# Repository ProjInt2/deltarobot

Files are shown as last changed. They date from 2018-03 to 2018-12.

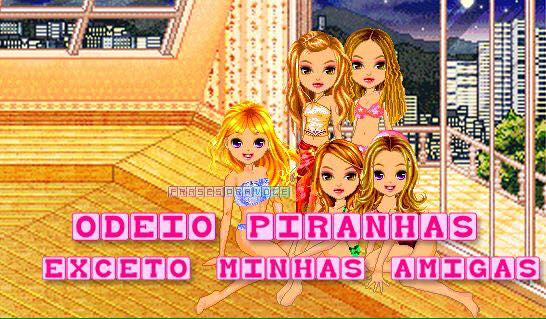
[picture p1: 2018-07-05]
sw/deltarobot-gui/res/amigas.jpg

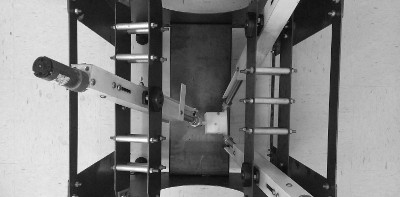
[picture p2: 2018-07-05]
sw/deltarobot-gui/res/menu-header.jpg

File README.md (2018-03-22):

# Delta Robot Actuation Project

*by Lucas Camargo, Soly Waltrick, and Willian Kenji Nishizawa*

This project consists in the development of a driving and control solution for a standard delta robot. It does not concern the development of the robot itself, or its actuators. It focuses on driving the actuators, control mechanisms, and required transducers (sensors).

The deliverables are organized in the following directories:

+ *datasheets* - documentation on different components used in the project
+ *fw* - controller + driver: board firmware
+ *hw* - controller + driver: hardware project
+ *report* - project report
+ *sw* - interface software for interacting with the controller board using a computer

*TODO: insert backref link to post*

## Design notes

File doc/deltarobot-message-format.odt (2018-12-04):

deltarobot Message Format and Parsing Library

Specification v1.0

Lucas Pires Camargo

EMB5613 – Projeto Integrado de Sistemas Embarcados

Prof. Diego Santos Greff

# Introduction

This document defines the message formats used by deltarobot. They are to be used in the implementation of both the firmware and the accompanying software interface.

For more information on the nature of the project and the robot itself, please refer to the full report.

## Purpose

The project aims for making the platform fully operational, which means giving the user means of controlling the platform position. This could be accomplished with an interface on the controller device itself, but we figure it is better (and more simply) done by use of a personal computer connected to the platform. This makes possible the use of an user interface with interactive 3D graphics, the creation of a software library for integration into other applications, path drawing, etc.

However, to accomplish this, there must be a standardized way for the controller to talk to a personal computer. Therefore, it was decided that a simple protocol would have to be defined.

## Definitions

In this specification, “Controller” means the device that operates the motors of the parallel actuators, reads sensor inputs, and executes the control loop. “Interface”, “Interface software”, or “Host” refers to the computer that is communicating with the Controller, monitoring its status, and defining its goal positions.

An “Opcode” is be understood as “Operation code”. Different Opcodes describe the various functionalities of the protocol in compartmentalized commands.

## About this specification

This document is organized as follows:

- Section “Connection and Transmission” gives an overview on the physical link layer.
- Section “Message Frame Structure” defines the basic structure of a command.
- Section “Opcodes” defines commands, their requirements and outcomes.
- Section “Implementation Notes” gives further details in regards to implementation and noteworthy behaviors.

# Connection and Transmission

The Controller is to be connected to the Host by means of a serial port device. This device has to be configured as follows:

- Baud rate: 115200 baud
- Data bits: 8 bits
- Stop bits: 1 bit
- Parity bits: (none)
- Hardware flow control: (disabled)

Furthermore, a “serial port”, this can mean a physical, standard RS-232 connection, or a connection emulated in software or in hardware. A valid implementation is a USB connection through which a serial data stream is sent, and that the Host can recognize as such. This has to translate into a COM port or TTY device file (“/dev/ttyS?”, “/dev/ttyUSB?”) in the operating system of the Host, to which the Interface Software connects.

Communication is full-duplex, that is, there can be a transmission occurring from both sides simultaneously. Every valid piece of communication is define in terms of “message frames”. A message frame is a group of bytes with a defined start and end, means for verification, and a specific purpose. The next section goes into detail about the structure of a message frame and related definitions.

# Message Frame Structure

Commands, status information, and control information are organized into frames. A frame is a validated sequence of bytes structured as follows:

Starter | Opcode | Data Length | Data | Checksum | Terminator
‘$’ (ASCII) | “What the frame is” | How many data bytes | Opcode-dependant | (See below) | ‘:’ (ASCII)
1 byte | 1 byte | 1 byte | (length – 5) bytes | 1 byte | 1 byte

- Starter: this marker (ASCII character ‘$’) denotes the beginning of a transmission frame. Both the Controller and the Host scan the incoming stream of bytes, expecting to find this marker. When it is found, decoding of a frame starts.
- Opcode: “operation-code”, a single byte from a predefined list. Individual opcodes are discussed in greater detail in a further section.
- Data Length: how many bytes of data the message contains. The value is usually tied to the opcode, but may vary (up to 255 bytes).
- Data: the data bytes of the message. Again, their meaning is opcode-specific.
- Checksum: a code that is calculated from the contents of the message. It is used to ascertain that the message has been received correctly. How the checksum is calculated is presented on the next section.
- Terminator: a single terminator byte (ASCII character ‘:’) that indicates the end of a message.

## Checksum Calculation

Checksums are calculated as a modular sum of all the bytes of the message, including starter and terminator. A modular sum is defined, in this context, as adding the bytes contents to an accumulator (initialized with zero), one after the other. Following every sum, the accumulator is set to its own value modulo 256.

This can be implemented by repeatedly summing the byte values to an unsigned byte variable.

## Notes

- There is no message resend requests.
- Incomplete or corrupted packets are lost.
- If an ACK times out, the operation request has to be repeated, depending on the opcode.

# Opcodes

This section describes each opcode in detail. However, for the purpose of an overview, a complete list is given beforehand. The opcodes are divided in three categories: “common” opcodes that can be sent in both directions, “down” opcodes that only make sense from Host to Controller, and “up” opcodes that only apply in the Controller to Host direction.

Following the lists of opcodes, there is a section explaining each opcode in detail.

## List of Common Opcodes

- Acknowledge – 0x41 – ASCII ‘A’
- No-Acknowledge – 0x4E – ASCII ‘N’

## List of Down Opcodes

- Homing Request – 0x48 – ASCII ‘H’
- Move Request – 0x4D – ASCII ‘M’
- Status Request – 0x53 – ASCII ‘S’
- Cancel Request – 0x43 – ASCII ‘C’

## List of Up Opcodes

- Homing Finished – 0x68 – ASCII ‘h’
- Move Finished – 0x6D – ASCII ‘m’
- Status Report – 0x73 – ASCII ‘s’
- General Error – 0x65 – ASCII ‘e’

## Acknowledge – 0x41 – ‘A’

Description: This opcode is a general acknowledgement (ack) message, to be issued in response to a previous request. It depends on the specific request (opcode) if it requires a corresponding ack or not. The message signifies that the request was understood, considered valid, and will be attempted to be fulfilled. If that is not the case, a No-Acknowledge (0x4E) is to be issued instead.

Data length: 1 byte

Data fields:

Data

Original Opcode

1 byte

There is only a single data field: one byte containing the opcode that prompted the Acknowledge.

Expected behavior: Opcode-specific. Generally none.

## No-Acknowledge – 0x4E – ‘N’

Description: This opcode is a general non-acknowledgement (nack) message, to be issued in response to a previous request. It depends on the specific request (opcode) if it requires a corresponding ack/nack or not. The message signifies that the request was not understood, considered invalid, or can’t be fulfilled at this current time. It is the negative alternative to the Acknowledge (0x41) opcode.

Data length: 1 byte

Data fields: There is only a single data field: one byte containing the opcode that prompted the NACK.

Data

Original Opcode

1 byte

## Homing Request – 0x48 – ‘H’

Description: This opcode is a request for the Controller to home in the actuators to a known default state. The specific behavior depends on the controller implementation, but is is expected to be something similar to retracting the arms until the stops are reached, defining the zero-movement state.

Data length: 0 bytes (none)

Data fields: This opcode has no associated data fields.

## Move Request – 0x4D – ‘M’

Description: This opcode is a request for the Controller to move the platform to a specified position. The path followed is expected to be linear.

Data length: TBD

Data fields: This opcode has the following data fields:

Data
DA – float | DB – float | DC – float
4 bytes | 4 bytes | 4 bytes

- Data field DA – displacement of arm “A” – 4 bytes – IEEE 32-bit float
- Data field DB – displacement of arm “B” – 4 bytes – IEEE 32-bit float
- Data field DC – displacement of arm “C” – 4 bytes – IEEE 32-bit float

## Status Request – 0x53 – ‘S’

Description: This opcode queries the Controller to send a status report message to the Host.

Data length: 0 bytes (none)

Data fields: This opcode has no associated data fields.

## Cancel Request – 0x43 – ‘C’

Description: This opcode requests the Controller to cancel the currently executing operation (Homing or Moving).

Data length: 0 bytes (none)

Data fields: This opcode has no associated data fields.

## Homing Finished – 0x68 – ASCII ‘h’

Description: This opcode informs the Host that the homing process has finalized.

Data length: 0 bytes (none)

Data fields: This opcode has no associated data fields.

## Move Finished – 0x6D – ASCII ‘m’

Description: This opcode informs the Host that the Controller moved the platform to the desired position.

Data length: 0 bytes (none)

Data fields: This opcode has no associated data fields.

## Status Report – 0x73 – ASCII ‘s’

Description: This opcode informs the Host of the current status of the Controller and the platform.

Data length: 13 bytes

Data fields: This opcode has the following data fields:

Data
STAT | DA – float | DB – float | DC – float
1 byte | 4 bytes | 4 bytes | 4 bytes

- STAT – Status bitmask – 1 byte
  - This byte is a bitmask containing information on the status of the platform:

STAT bits
7 | 6 | 5 | 4 | 3 | 2 | 1 | 0
RESERVED | RESERVED | RESERVED | STPC | STPB | STPA | ST1 | ST0

  - ST[0..1]: Status bits
    - Value 00: Platform is Idle
    - Value 01: Platform is Homing
    - Value 10: Platform is Moving
    - Value 11: Platform is at Error
  - STPA: bit indicating the status of the end-of-course switch of arm A.
    - Value 1: pressed
    - Value 0: not pressed
  - STPB: bit indicating the status of the end-of-course switch of arm B (1 means pressed).
  - STPC: bit indicating the status of the end-of-course switch of arm C (1 means pressed).
  - Bits 5-7 are reserved for use in future revisions.
- Data field DA – displacement of arm “A” – 4 bytes – IEEE 32-bit float
- Data field DB – displacement of arm “B” – 4 bytes – IEEE 32-bit float
- Data field DC – displacement of arm “C” – 4 bytes – IEEE 32-bit float

Note: If any arm displacement field is a NAN value, the arm position is unknown, and the Controller requires a Homing operation.

## General Error – 0x65 – ASCII ‘e’

Description: This opcode informs the Host that the platform has encountered an error and the current operation cannot continue.

Data length: 0 bytes (none)

Data fields: This opcode has no associated data fields.

# Parsing Library

The reference implementation of the protocol is a portable “pure-C” function library with no external dependencies, not even on the C standard library. This makes it suitable not only for use on a desktop application, but also for the controller firmware. Using the same implementation on both ends of the communication simplifies implementation on both ends and ensures code consistency.

The library is comprised of two files, a “.h” header and a “.c” source. Both files can be included in a source file for convenience, provided the definition.

## Usage

The library provides facilities for sending, parsing and receiving frames. It is comprised of two main data structures, some definitions, and three functions. The definitions and functions are covered in the following sections.

The first structure is protocol_data, a circular buffer used for storing streamed bytes for parsing. The function dp_process() function is used to add bytes to the buffer, and the dp_recv() function attempts to parse bytes of the buffer into a message.

A message is stored in the protocol_msg. The function dp_recv() stores a received message in it, and the function

The following section goes into the library interface in greater detail.

## Interface

### Return Codes

The library defines common integer return codes for the functions. According to C convention, a function returning 0 usually means the operation completed successfully or returned something meaningful.

The return code definitions start with the DP_RC_ prefix.

Return Code | Description
DP_RC_SUCCESS | The operation completed successfully.
DP_RC_ERROR_GENERIC | There was an error completing the operation.
DP_RC_NO_FRAME | No frame was available in the buffer.
DP_RC_OVERFLOW | Some buffer contents were lost because an overflow occurred.
DP_RC_GARBAGE | There was garbage in the buffer and no frame could be parsed.

### Functions

Return Code | Description
dp_process() | Insert incoming bytes into a protocol_data structure. Arguments: protocol_data *data → which buffer to insert data in int bytes → how many bytes to insert void *buf → where the data is
dp_recv() | Analyzes protocol data to look for a message, possibly returning it. Arguments: protocol_data *data → which buffer to parse from protocol_msg *msg → the message to fill out with parsed data
dp_send() | Sends a message using the given send function. Arguments: protocol_msg *msg → the message to be sent send_func_t f → the function that will be fed with the resulting stream bytes void *usr → opaque pointer that will be forwarded as an argument to the send function

### Structure protocol_msg

Type | Field | Description
uint8_t | opcode | Message opcode.
int | data_s | How many data bytes the message has.
char[32] | data | Data bytes of the message
int | checksum_ok | Flag indicating if the checksum was correct when parsed.

### Structure protocol_data

Type | Field
uint8_t | opcode
int | data_s
char[32] | data

### Other definitions

Identifier | Description
send_func_t | Type definition the the send function used by dp_send(). Defined as: typedef int (*send_func_t)(void *buf, int bytes, void *usr);
DP_PROTO_FRAME_START | Frame start marker (‘$’)
DP_PROTO_FRAME_END | Frame end marker (‘:’)
DP_PROTO_ALL_OPCODES | Character string containing all valid opcodes.
DP_OPCODE_ACK DP_OPCODE_NACK DP_OPCODE_HOMING DP_OPCODE_STATUS DP_OPCODE_MOVE DP_OPCODE_CANCEL DP_OPCODE_HOMING_REPL DP_OPCODE_STATUS_REPL DP_OPCODE_MOVE_REPL DP_OPCODE_GENERAL_ERR | Defines for every single opcode, for ease of use of the library.

## Examples

The library includes two example programs, in the tests/ directory.

- “cross_comm.cpp” → instantiates several library structures and sends messages back and forth, testing the main functionality in thre process.
- “send_opcode.cpp” → sends a simple ACKNOWLEDGE message on the serial port, to test basic communication functions.

deltarobot Message Format – spec v1.0 Page 11 of 11

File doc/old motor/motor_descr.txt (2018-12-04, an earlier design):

Boa tarde, 
Sou Lucas Camargo, aluno de Engenharia Mecatrônica da UFSC. Recebi seu contato por meio do Prof. Diego Greff. Ele deve ter mencionado a nossa necessidade de adquirir um motor similar a um que tínhamos em um projeto legado do laboratório. É um modelo pequeno com caixa de redução. Ocorreu dano ao rolamento do motor original , e na tentativa de conserto, as escovas foram quebradas.
Infelizmente não temos as informações de chapa dele, porque é antigo e isso se perdeu. A única informação que temos é o fabricante, Bühler. Porém posso dar algumas características gerais e fotos: 
- Comprimento do enrolamento: 45 mm
- Diâmetro do enrolamento: 20 mm
- Comprimento do íma permanente: 37 mm
- Diâmetro da carcaça: 30 mm

A ideia é encontrar um motor (ou três deles - para uma máquina paralela) que seja parecido.
Desde já já agradeço a atenção.

att,
Lucas

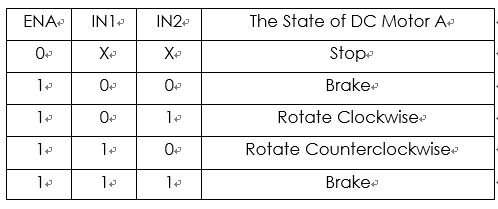
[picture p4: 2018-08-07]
datasheets/l298n-module/Motor Driver Module-L298N - Wiki_arquivos/Motor5.png

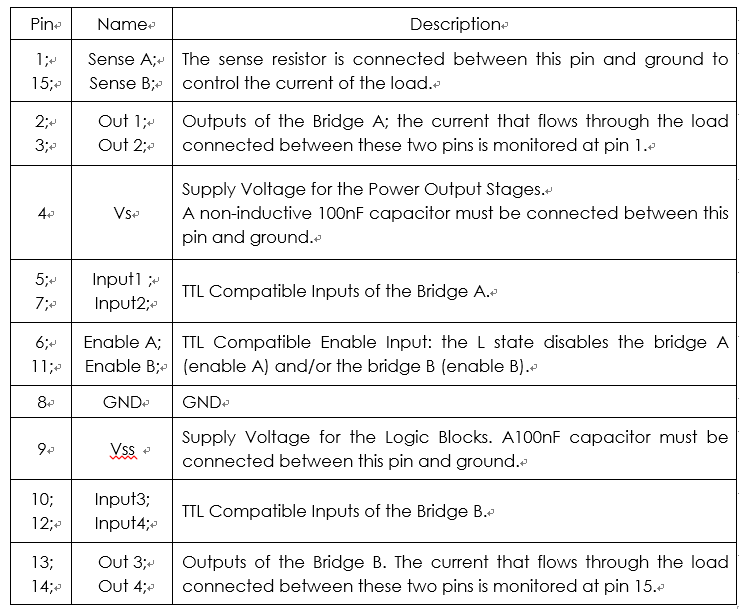
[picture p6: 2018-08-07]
datasheets/l298n-module/Motor Driver Module-L298N - Wiki_arquivos/Motor4.png

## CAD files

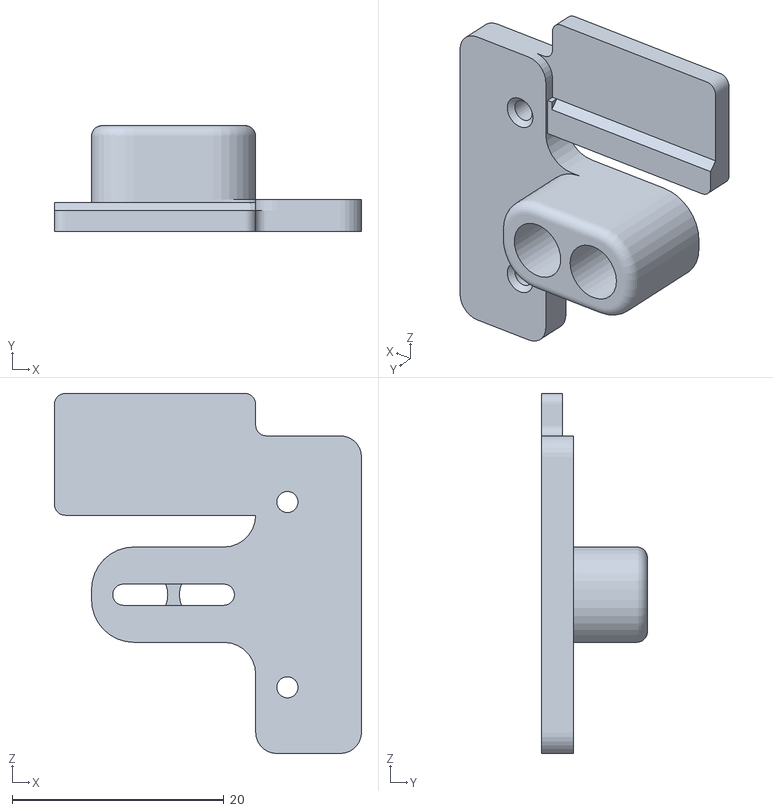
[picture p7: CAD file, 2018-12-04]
mec/optical_sw_holder_no_pins_larger_holes.stl
29.0 x 10.0 x 34.0

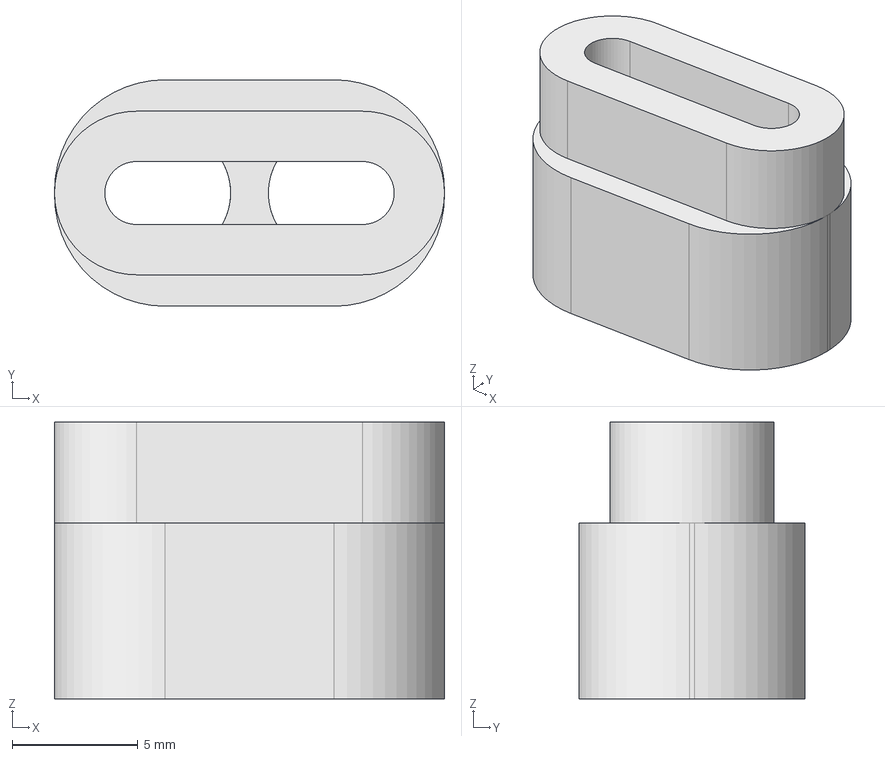
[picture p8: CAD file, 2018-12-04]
mec/optical_holder.fcstd
15.5 x 9.00 x 11.0 mm

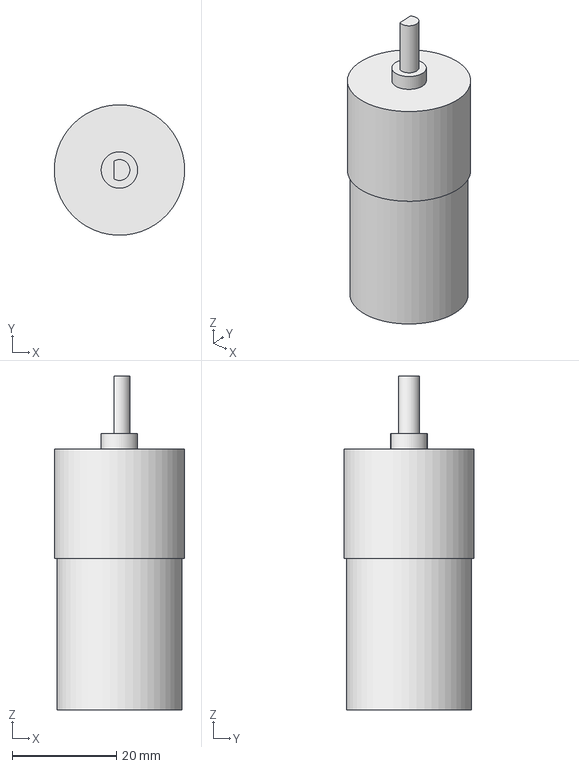
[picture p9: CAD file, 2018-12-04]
mec/motor.fcstd
25.0 x 25.0 x 64.0 mm

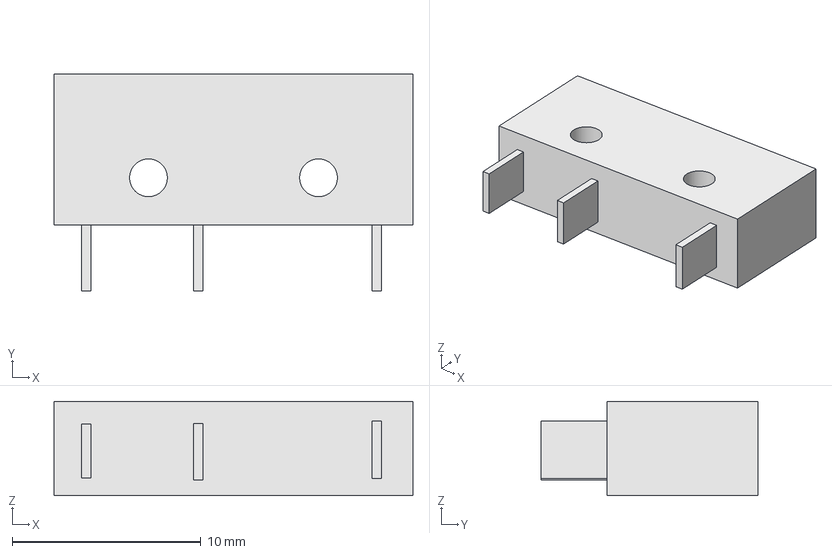
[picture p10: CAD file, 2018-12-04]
mec/stopper_sw.fcstd
19.0 x 11.5 x 5.00 mm

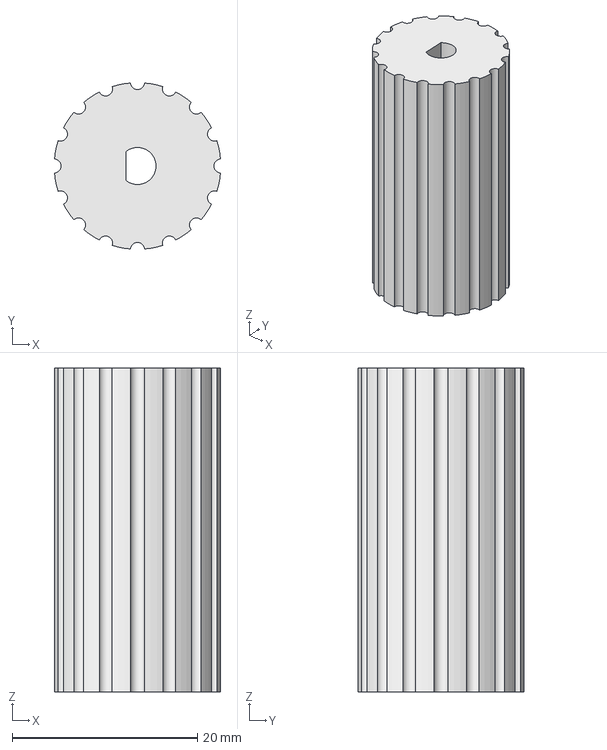
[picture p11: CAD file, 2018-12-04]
mec/axle_adapter.fcstd
17.9 x 17.9 x 35.0 mm

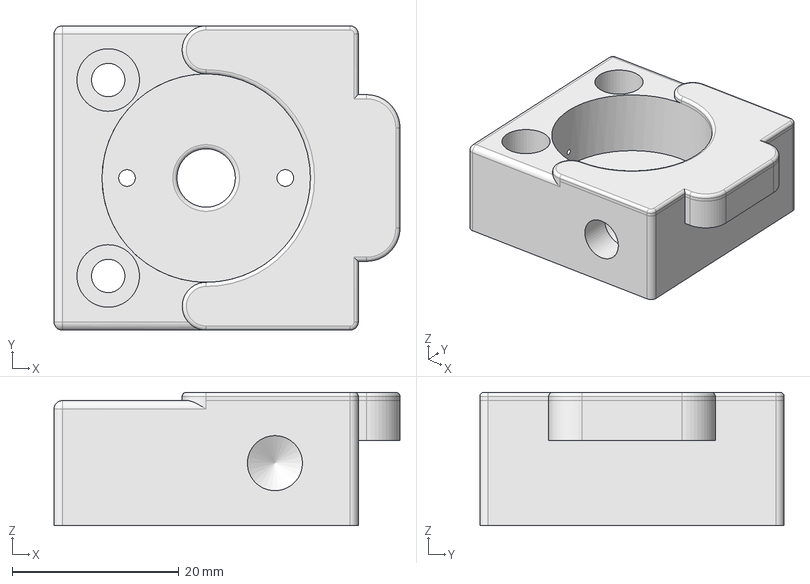
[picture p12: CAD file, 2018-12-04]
mec/stopper.fcstd
41.5 x 36.5 x 16.0 mm

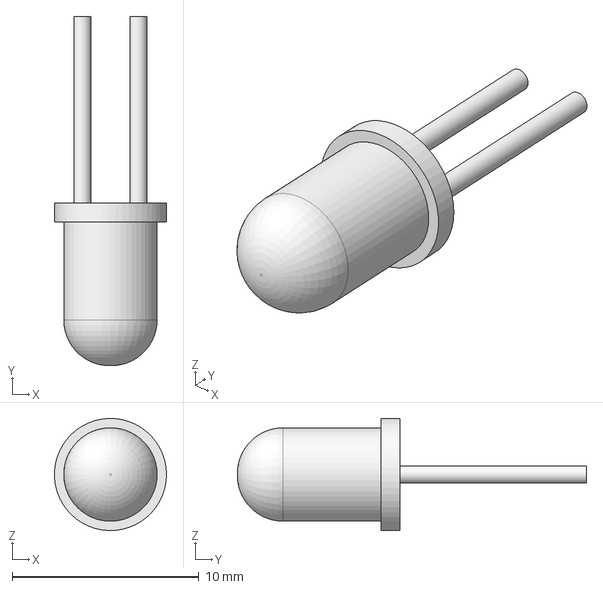
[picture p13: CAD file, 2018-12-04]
mec/led5mm.fcstd
5.99 x 18.7 x 6.00 mm

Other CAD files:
mec/assembly.fcstd
mec/optical_sw_holder_no_pins.stl
mec/optical_sw_holder.fcstd
mec/optical_sw_holder.stl

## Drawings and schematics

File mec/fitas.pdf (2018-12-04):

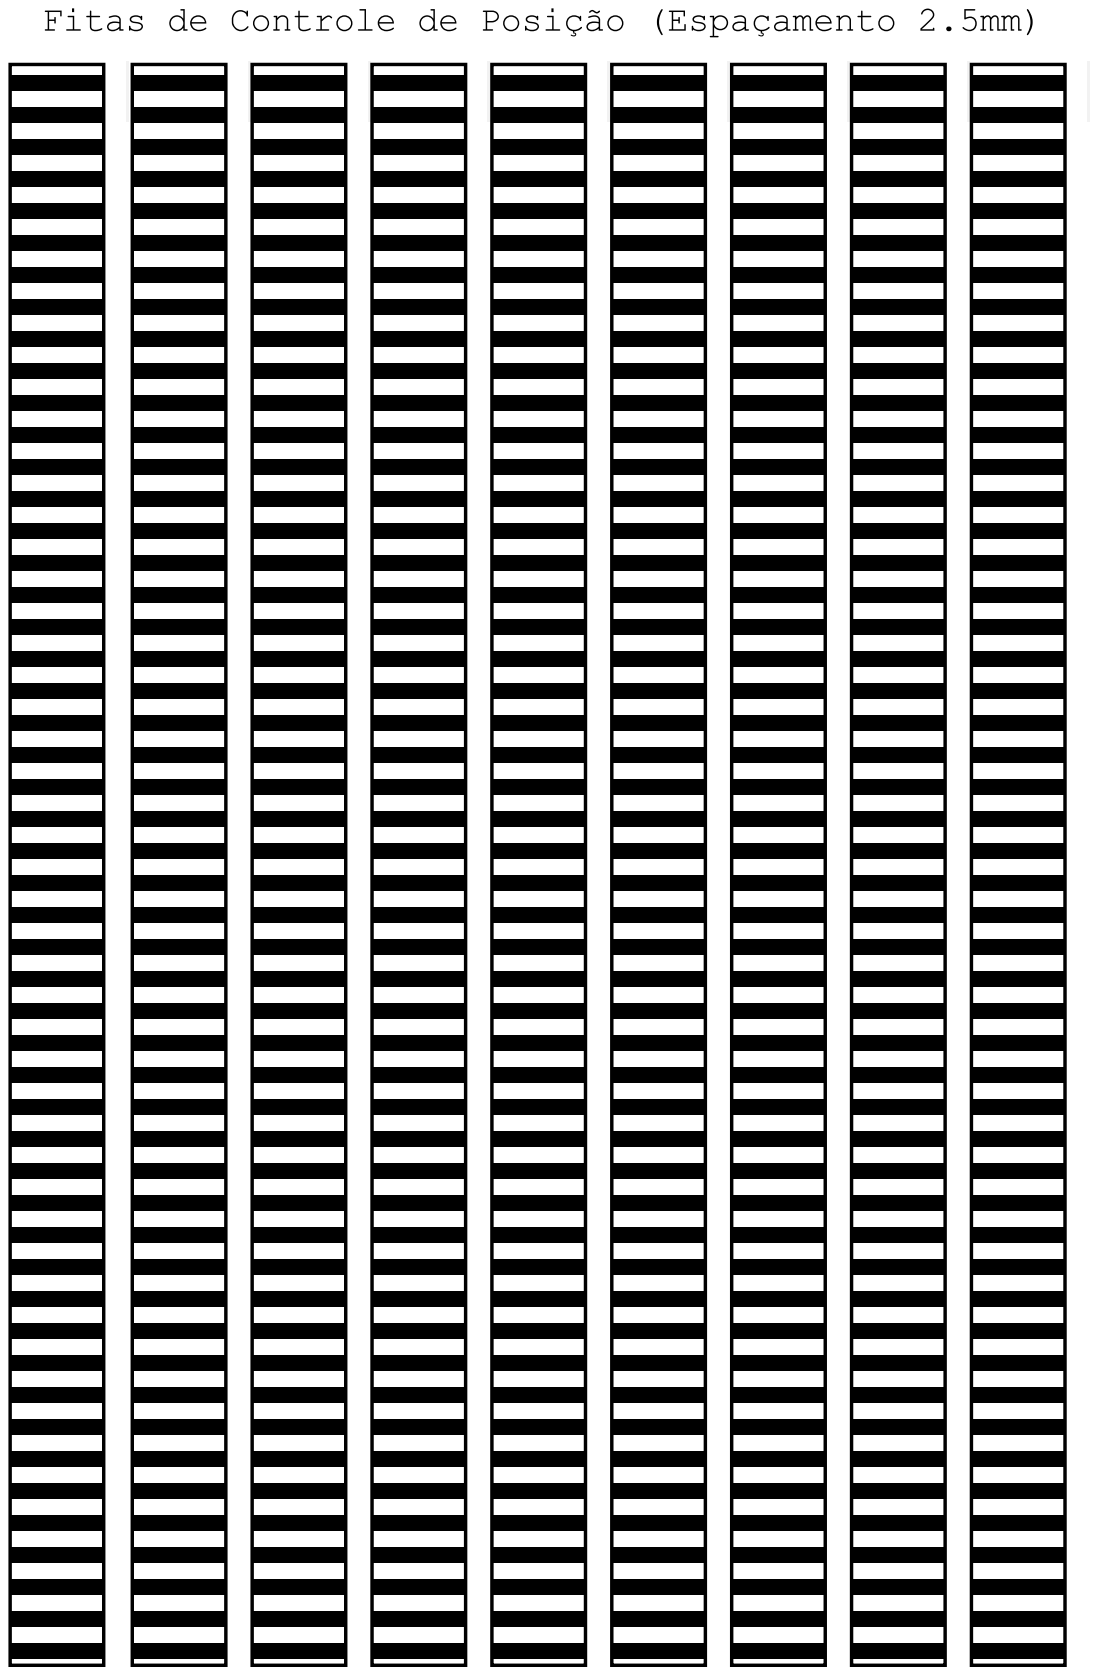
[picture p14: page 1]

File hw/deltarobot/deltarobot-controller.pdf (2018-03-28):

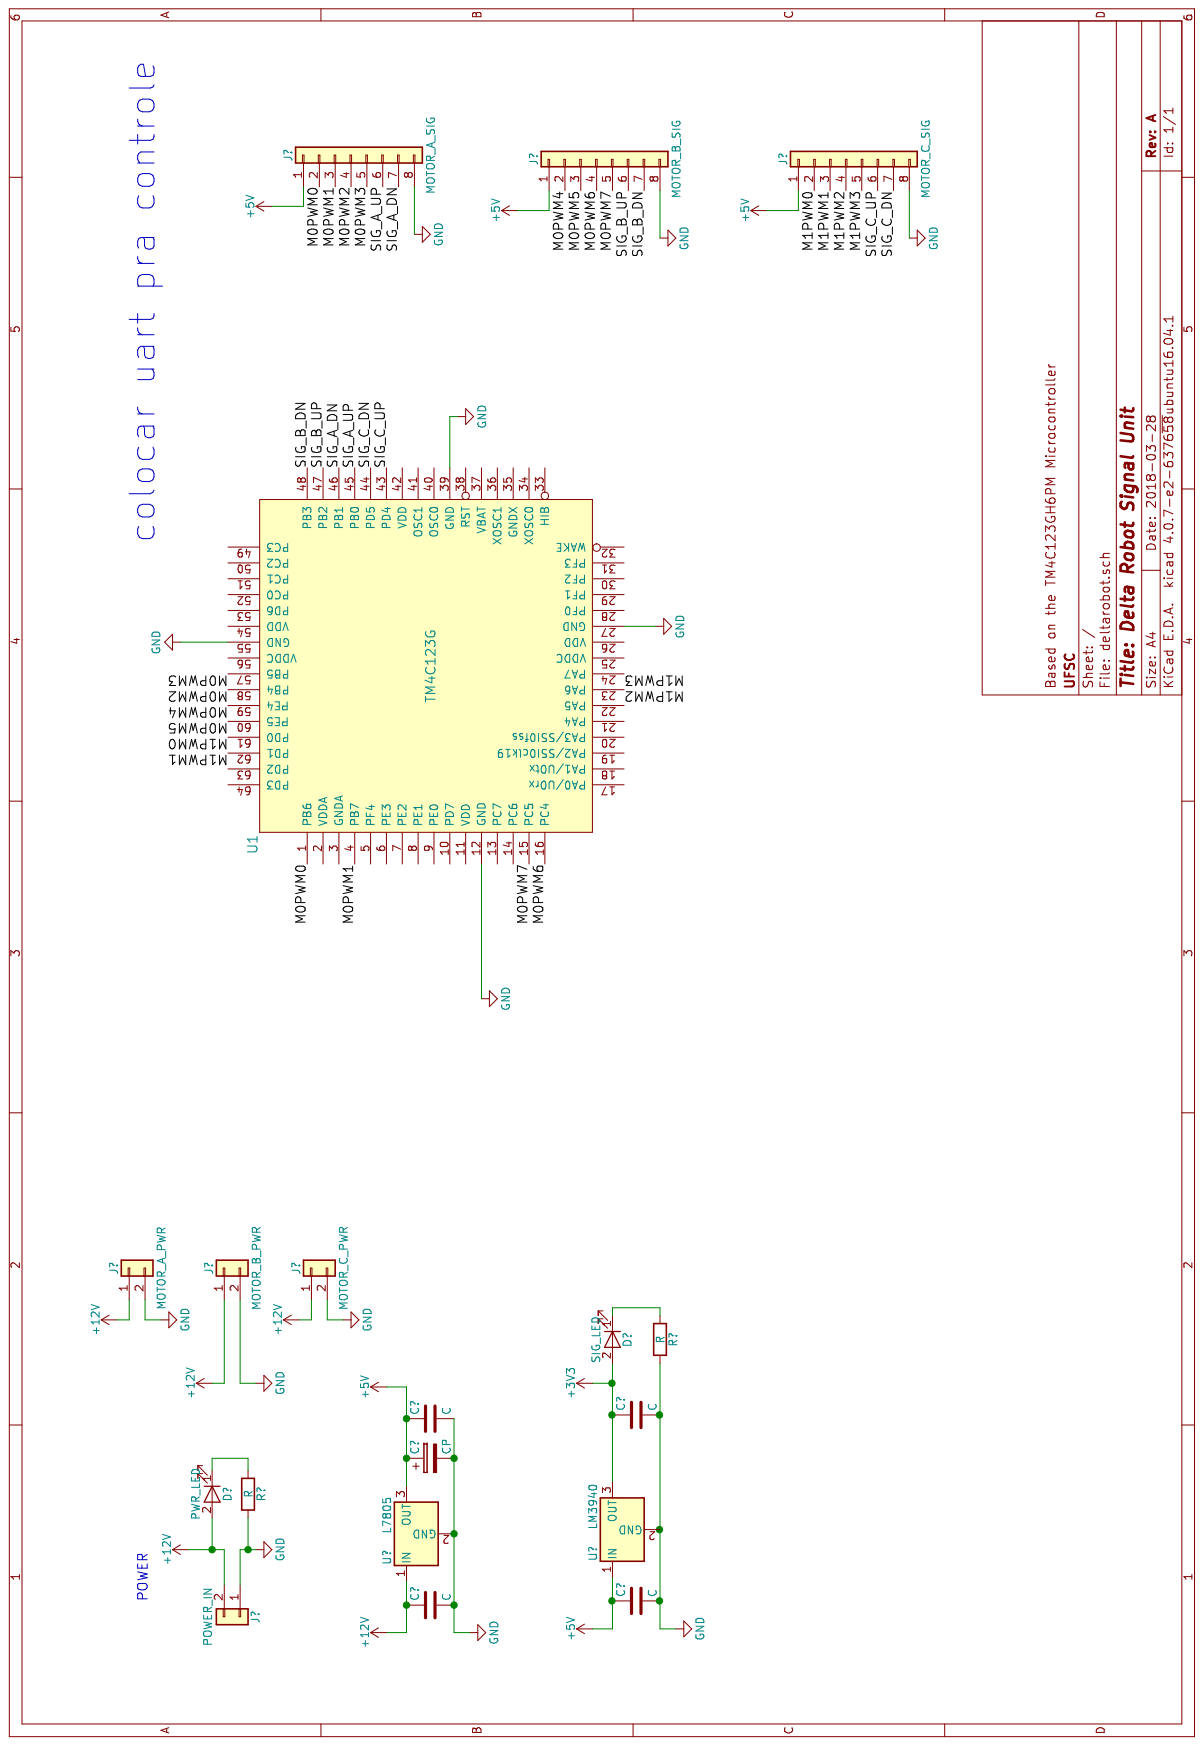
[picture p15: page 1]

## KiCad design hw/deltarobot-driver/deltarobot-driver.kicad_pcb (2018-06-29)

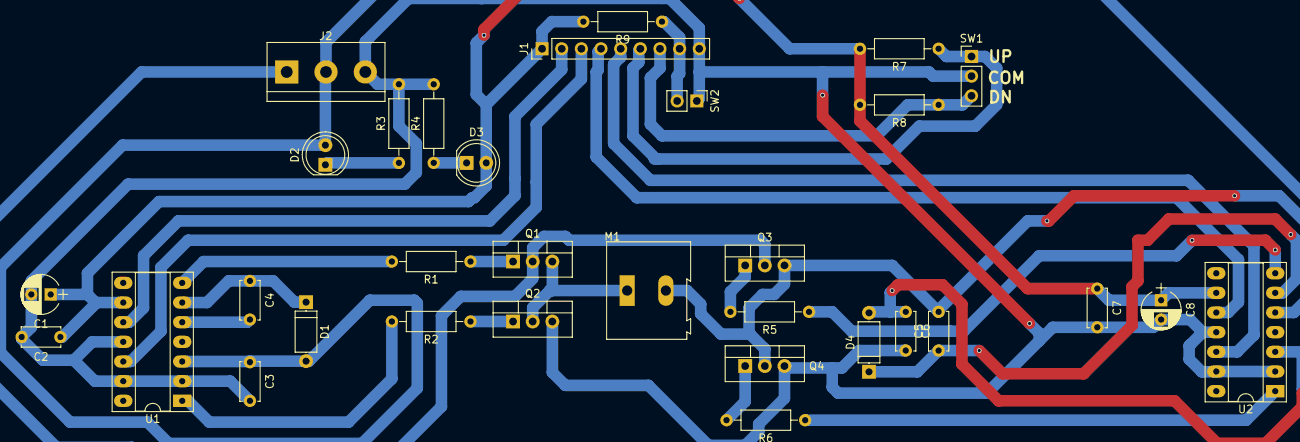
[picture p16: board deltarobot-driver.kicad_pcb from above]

Board: 2 copper layers, 32 parts (0 on the bottom side), 25 nets.

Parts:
C1, C8: .47uF; CP_Radial_D5.0mm_P2.50mm
C2, C7: .1uF; C_Disc_D5.0mm_W2.5mm_P5.00mm
C3, C6: 2.2u; C_Disc_D5.0mm_W2.5mm_P5.00mm
C4, C5: 100u; C_Disc_D5.0mm_W2.5mm_P5.00mm
D1, D4: D; D_A-405_P7.62mm_Horizontal
D2: LED_vcc; LED_D5.0mm
D3: LED_vdd; LED_D5.0mm
J1: CONN_SIG; Pin_Header_Straight_1x09_Pitch2.54mm
J2: CONN_PWR; TerminalBlock_bornier-3_P5.08mm
M1: Motor_DC; TerminalBlock_Altech_AK300-2_P5.00mm
Q1, Q2, Q3, Q4: IRFZ44N; TO-220-3_Vertical
R1, R2, R5, R6: 0R; R_Axial_DIN0207_L6.3mm_D2.5mm_P10.16mm_Horizontal
R3, R4: R; R_Axial_DIN0207_L6.3mm_D2.5mm_P10.16mm_Horizontal
R7, R8, R9: 10k; R_Axial_DIN0207_L6.3mm_D2.5mm_P10.16mm_Horizontal
SW1: Rotary_Encoder; Pin_Header_Straight_1x03_Pitch2.54mm
SW2: SW_STOP; Pin_Header_Straight_1x02_Pitch2.54mm
U1, U2: IR2010; DIP-14_W7.62mm_Socket_LongPads

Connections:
+12V: J2.1, Q1.2, Q3.2
/Ha: J1.2, U1.10
/Hb: J1.4, U2.10
/La: J1.3, U1.12
/Lb: J1.5, U2.12
/Sdn: J1.7, R8.1, SW1.3
/Sstop: J1.8, R9.1, SW2.2
/Sup: J1.6, R7.1, SW1.1
GND: C1.2, C2.2, C3.2, C6.2, C7.2, C8.2, J1.9, J2.3, Q2.3, Q4.3, R3.2, R4.2, SW1.2, SW2.1, U1.2, U1.11, U1.13, U2.2, U2.11, U2.13
unnamed: C4.1, D1.1, U1.6
unnamed: C4.2, M1.1, Q1.3, Q2.2, U1.5
unnamed: C5.1, D4.1, U2.6
unnamed: C5.2, M1.2, Q3.3, Q4.2, U2.5
unnamed: D2.1, R3.1
unnamed: D3.1, R4.1
unnamed: Q1.1, R1.1
unnamed: Q2.1, R2.1
unnamed: Q3.1, R5.2
unnamed: Q4.1, R6.2
unnamed: R1.2, U1.7
unnamed: R2.2, U1.1
unnamed: R5.1, U2.7
unnamed: R6.1, U2.1
VCC: C3.1, C6.1, D1.2, D2.2, D4.2, J2.2, U1.3, U2.3
VDD: C1.1, C2.1, C7.1, C8.1, D3.2, J1.1, R7.2, R8.2, R9.2, U1.9, U2.9

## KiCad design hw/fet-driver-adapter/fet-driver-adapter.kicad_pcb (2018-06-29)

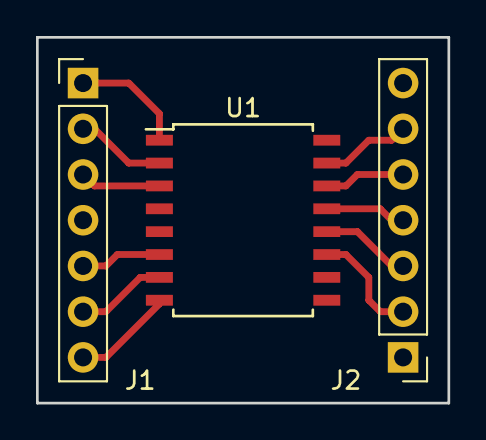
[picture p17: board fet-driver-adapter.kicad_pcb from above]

Board: 2 copper layers, 22.9 x 20.3 mm, 3 parts (0 on the bottom side), 11 nets.

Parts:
J1: DIP_1_7; Pin_Header_Straight_1x07_Pitch2.54mm
J2: DIP_8_14; Pin_Header_Straight_1x07_Pitch2.54mm
U1: IR210x; SOIC-16W_7.5x10.3mm_Pitch1.27mm

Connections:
/COM: J1.2, U1.2
/HIN: J2.3, U1.12
/HO: J1.7, U1.8
/LIN: J2.5, U1.14
/LO: J1.1, U1.1
/SD: J2.4, U1.13
/VB: J1.6, U1.7
/VS: J1.5, U1.6
/Vcc: J1.3, U1.3
/Vdd: J2.2, U1.11
/Vss: J2.6, U1.15

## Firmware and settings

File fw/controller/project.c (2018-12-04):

#define PART_TM4C123GH6PM 1

#include "libcamargo/common.h"
#include "libcamargo/led.h"
#include "libcamargo/pwm_mock.h"

#include "driverlib/pin_map.h"
#include "driverlib/uart.h"
#include "driverlib/gpio.h"
#include "./libdeltarobot/protocol.h"
#define PROTOCOL_C_NO_INCLUDE
#include "./libdeltarobot-src/protocol.c"

#ifdef DEBUG
void
__error__(char *pcFilename, uint32_t ui32Line)
{
}
#endif

float getnan()
{
    union
    {
        int the_int;
        float the_float;
    } nanunion;
    
    nanunion.the_int = 0x7F800001;
    return nanunion.the_float;
}

void my_memcpy(void* dst, void* src, int bytes)
{
    unsigned char * const dstBytes = (unsigned char *) dst;
    unsigned char * const srcBytes = (unsigned char *) src;
    for(int i = 0; i < bytes; i++)
        dstBytes[i] = srcBytes[i];    
}

int is_nan(float arg)
{
    if(arg != arg)  // certainly a nan
        return 1;
    
    return arg == getnan();
}

int pwm_alpha_to_period( float alpha )
{
    return (PWM_PERIOD/2) + (alpha*(PWM_PERIOD/2));
}


// GLOBALS
struct protocol_data pdata;
int curr_status;
unsigned int curr_led;

int pwmEnable;
float pwmValues[3];  // -1 .. +1
float currPos[3];
float goalPos[3];

#define POSITION_TOLERANCE 0.126f // mm

void setup_vars()
{
    // initialize pdata struct
    pdata.m_idx = 0;
    pdata.m_sz = 0;
    
    curr_status = DP_STATUS_IDLE;
    curr_led = LED_G;
    
    pwmEnable = 0;
    
    for(int i = 0; i < 3; i++)
    {
        pwmValues[i] = 0.0f;
        currPos[i] = getnan();
    }
}

int is_position_known()
{
    return (!is_nan(currPos[0])) && (!is_nan(currPos[1])) && (!is_nan(currPos[2])); 
}


// UART DEFINES
#define BAUDRATE  115200
void UART0Handler();
int uart_send(void *buf, int bytes, void *usr);

void setup_uart()
{
    SysCtlPeripheralEnable(SYSCTL_PERIPH_UART0);
    SysCtlPeripheralEnable(SYSCTL_PERIPH_GPIOA);
    GPIOPinConfigure(GPIO_PA0_U0RX);
    GPIOPinConfigure(GPIO_PA1_U0TX);
    GPIOPinTypeUART(GPIO_PORTA_BASE, GPIO_PIN_0 | GPIO_PIN_1);
    
    UARTConfigSetExpClk(UART0_BASE, SysCtlClockGet(), BAUDRATE, (UART_CONFIG_WLEN_8 | UART_CONFIG_STOP_ONE | UART_CONFIG_PAR_NONE));
    
    UARTIntRegister( UART0_BASE, UART0Handler );
    UARTIntEnable( UART0_BASE, UART_INT_RX | UART_INT_TX );
}

int uart_send_func(void *data, int size, void* usr)
{
    (void) usr;
    unsigned char *dataBytes = (unsigned char *) data;
    for(int i = 0; i < size; i++)
        UARTCharPut(UART0_BASE, dataBytes[i]);
    return 0;
}


// STOPS DEFINES

#define STOP_A             GPIO_PIN_0
#define STOP_B             GPIO_PIN_1
#define STOP_C             GPIO_PIN_2
#define STOPS_ALL             (STOP_A | STOP_B | STOP_C | GPIO_PIN_3)

int32_t stops_status = 0;

// returns true if something changed
int read_stops()
{
    int32_t prev = stops_status;
    int32_t stops_status_port = GPIOPinRead(GPIO_PORTE_BASE, STOPS_ALL);


    stops_status =      (stops_status_port & STOP_A? (1 << 0) : 0) |
                        (stops_status_port & STOP_B? (1 << 1) : 0) |
                        (stops_status_port & STOP_C? (1 << 2) : 0);

    return prev ^ stops_status;
}

void setup_stops()
{
    SysCtlPeripheralEnable(SYSCTL_PERIPH_GPIOE);
    GPIODirModeSet(GPIO_PORTE_BASE, STOPS_ALL, GPIO_DIR_MODE_IN);
    GPIOPadConfigSet(GPIO_PORTE_BASE, STOPS_ALL, GPIO_STRENGTH_2MA, GPIO_PIN_TYPE_STD_WPU);
    read_stops();
}


// ENCODER DEFINES

#define ENC_A             GPIO_PIN_3
#define ENC_B             GPIO_PIN_3
#define ENC_C             GPIO_PIN_2
#define ENC_ALL           (ENC_A | ENC_B | ENC_C)

int32_t encoders_status = 0;

// returns true if something changed
int read_encoders()
{
    int32_t prev = encoders_status;
    int32_t encoders_status_portd = GPIOPinRead(GPIO_PORTD_BASE, ENC_A | ENC_C);
    int32_t encoders_status_portb = GPIOPinRead(GPIO_PORTB_BASE, ENC_B);

    encoders_status =   (encoders_status_portd & ENC_A? (1 << 0) : 0) |
                        (encoders_status_portb & ENC_B? (1 << 1) : 0) |
                        (encoders_status_portd & ENC_C? (1 << 2) : 0);

    return prev ^ encoders_status; // if something changed
}

void setup_encoders()
{
    SysCtlPeripheralEnable(SYSCTL_PERIPH_GPIOD);
    GPIOPinTypeGPIOInput(GPIO_PORTD_BASE, ENC_A | ENC_C);
    GPIODirModeSet(GPIO_PORTD_BASE, ENC_A | ENC_C, GPIO_DIR_MODE_IN);
    GPIOPadConfigSet(GPIO_PORTD_BASE, ENC_A | ENC_C, GPIO_STRENGTH_2MA, GPIO_PIN_TYPE_STD_WPU);


    SysCtlPeripheralEnable(SYSCTL_PERIPH_GPIOB);
    GPIOPinTypeGPIOInput(GPIO_PORTB_BASE, ENC_B);
    GPIODirModeSet(GPIO_PORTB_BASE, ENC_B, GPIO_DIR_MODE_IN);
    GPIOPadConfigSet(GPIO_PORTB_BASE, ENC_B, GPIO_STRENGTH_2MA, GPIO_PIN_TYPE_STD_WPU);

    read_encoders();
}



// FUNCTIONS

void send_ack(unsigned int opcode)
{   
    struct protocol_msg msg;
    msg.opcode = DP_OPCODE_ACK;
    msg.data_s = 1;
    msg.data[0] = opcode;
    dp_send(&msg, &uart_send_func, 0);
}

void send_nack(unsigned int opcode)
{   
    struct protocol_msg msg;
    msg.opcode = DP_OPCODE_NACK;
    msg.data_s = 1;
    msg.data[0] = opcode;
    dp_send(&msg, &uart_send_func, 0);
}

void send_status()
{
    struct protocol_msg_status_report rep;
    rep.DA = currPos[0];
    rep.DB = currPos[1];
    rep.DC = currPos[2];
    rep.STAT = ((~stops_status) << 2) | (curr_status & 0x03);
    
    struct protocol_msg msg;
    msg.opcode = DP_OPCODE_STATUS_REPL;
    msg.data_s = sizeof(rep);
    my_memcpy(msg.data, &rep, sizeof(rep));
    
    dp_send(&msg, &uart_send_func, 0);
}

void process_messages()
{
    while(UARTCharsAvail(UART0_BASE)) 
    {
        uint8_t c = UARTCharGet(UART0_BASE);
        
        dp_process(&pdata, &c, 1);
    }
    
    struct protocol_msg pmsg;
    struct pos_s_t { float DA, DB, DC; } *pos;
    if(!dp_recv(&pdata, &pmsg))
    {
        // received a message
        
        switch(pmsg.opcode)
        {
            case DP_OPCODE_ACK:
                cLedSet(LED_B | LED_G);
                break;
            case DP_OPCODE_NACK:
                cLedSet(LED_R);
                break;
            case DP_OPCODE_HOMING:
                {
                    // host wants us to go home
                    if(curr_status != DP_STATUS_ERROR)
                    {
                        curr_status = DP_STATUS_HOMING;
                        curr_led = LED_G | LED_B;
                        send_ack(DP_OPCODE_HOMING);
                    }
                    else send_nack(DP_OPCODE_HOMING);
                    
                    send_status();
                }
                break;
            case DP_OPCODE_STATUS:
                send_status();
                break;

            case DP_OPCODE_MOVE:
                {
                    if(!is_position_known())
                    {
                        send_nack(DP_OPCODE_MOVE);
                        break;
                    }   
                    
                    // host wants us to go home
                    if(curr_status != DP_STATUS_ERROR && pmsg.data_s == sizeof(struct pos_s_t))
                    {
                        pos = (struct pos_s_t*) pmsg.data;
                        if(is_nan(pos->DA) || is_nan(pos->DB) || is_nan(pos->DC) )
                        {
                            send_nack(DP_OPCODE_MOVE);
                        }
                        else
                        {
                            goalPos[0] = pos->DA;
                            goalPos[1] = pos->DB;
                            goalPos[2] = pos->DC;
                            curr_status = DP_STATUS_MOVING;
                            send_ack(DP_OPCODE_MOVE);
                        }
                    }
                    else send_nack(DP_OPCODE_MOVE);
                    
                    send_status();
                }
                break;
            case DP_OPCODE_CANCEL:
                curr_led = (LED_R | LED_G);
                if(curr_status != DP_STATUS_ERROR)
                {
                    curr_status = DP_STATUS_IDLE;
                    send_ack(DP_OPCODE_CANCEL);
                }
                else send_nack(DP_OPCODE_CANCEL);
                send_status();
                break;
            default:
                cLedSet(0); // this might not go through if not a valid opcode
                break;
        }
    }
}


void move_step()
{
    for( int i = 0; i < 3; i++)
    {
        float diff = goalPos[i] - currPos[i];
        float diffAbs = diff < 0? -diff : diff;

        if(diffAbs > POSITION_TOLERANCE)
        {
            // difference in position, use pwm
            pwmValues[i] = diff > 0? 1.0f : -1.0f;

            if(pwmValues[i] > 0)
            {
                // going forward
                pwmEnable |= (1 << i);
            }
            else
            {
                // going back
                if(stops_status & (1 << i))
                    pwmEnable |= (1 << i);
                else
                    pwmEnable &= ~(1 << i); // disable going back when stop is triggered
            }
        }
        else
        {
            pwmEnable &= ~(1 << i);
            pwmValues[i] = 0.0f;
        }
    }

    if(!(pwmEnable & 0x07))
    {
        curr_status = DP_STATUS_IDLE;
        send_status();
    }
}

void update_pwm()
{
    switch(curr_status)
    {
        case DP_STATUS_HOMING:
            if(!stops_status)
            {
                pwmEnable = 0x00;
                curr_status = DP_STATUS_IDLE;
                currPos[0] = currPos[1] = currPos[2] = 0.0f;
                send_status();
            }
            else
            {
                pwmEnable = stops_status; // bit in stops_status is zero if pressed
                pwmValues[0] = -1.0f;
                pwmValues[1] = -1.0f;
                pwmValues[2] = -1.0f;
            }
            break;
            send_status();

        case DP_STATUS_MOVING:
            move_step();
            break;

        default:
            pwmEnable = 0;
            break;
            
    }

    cPWMSet( pwmEnable, pwm_alpha_to_period(pwmValues[0]),
             pwm_alpha_to_period(pwmValues[1]), pwm_alpha_to_period(pwmValues[2]) );

    // home in, for testing
    //cPWMSet( stops_status, 0, 0, 0 ); // set pwm output values

    // advance, for testing
    //cPWMSet( 0xff, PWM_PERIOD, PWM_PERIOD, PWM_PERIOD ); // set pwm output values
}


// MAIN - SETUP

inline void setup()
{
    setup_vars();
    
    // INIT PWM
    if(cPWMInit())
        curr_status = DP_STATUS_ERROR;

    setup_uart();    
    setup_stops();
    setup_encoders();
}


// MAIN - LOOP

void loop()
{
    SysCtlDelay( 20000 ); // control delay
    
    read_stops();
    
    process_messages();
    update_pwm();   

    // heartbeat
    static int counter = 0;
    counter ++;
    cLedSet( (counter/10)%2? curr_led : 0 );
    

    /* SIMULATE DISTANCE
    if((!(counter % 500)) && (curr_status == DP_STATUS_HOMING || curr_status == DP_STATUS_MOVING))
    {
        if(pwmEnable & 1)
            if(pwmValues[0] < 0)
                currPos[0] -= 2.5f;
            if(pwmValues[0] > 0)
                currPos[0] += 2.5f;

        if(!(counter % 1000))
        {
            for( int i = 1; i < 3; i++)
            {
                if(pwmEnable & (1 << i))
                    if(pwmValues[i] < 0)
                        currPos[i] -= 2.5f;
                    if(pwmValues[i] > 0)
                        currPos[i] += 2.5f;
            }
        }


        send_status();
    }*/

    static uint32_t prev_enc_status = 0;
    static int enc_ticks[3] = {0,0,0};
    static uint32_t enc_changes = 0;

    if(curr_status == DP_STATUS_MOVING)
    {

        for(int i = 0; i < 3; i++)
        {
            enc_ticks[i] ++;
        }

        if(read_encoders())  // changes happened within the encoders
        {
            uint32_t enc_changes = prev_enc_status ^ encoders_status;

            for(int i = 0; i < 3; i++)
            {
                if(enc_changes & (1 << i))
                {
                    // encoder changed state, see if enough time to consider a genuine change and not just noise
                    if(enc_ticks[i] > 45)
                    {
                        if(pwmEnable & (1 << i))
                        {
                            // currPos[i] = enc_ticks[i];  -- for testing

                            if(pwmValues[i] < 0)
                                currPos[i] -= 2.5f;
                            if(pwmValues[i] > 0)
                                currPos[i] += 2.5f;
                        }

                        send_status();
                    }
                    enc_ticks[i] = 0; // reset counter on change
                }
            }
        }

        curr_led = ((encoders_status&1?LED_R:0)|(encoders_status&1?LED_G:0)|(encoders_status&1?LED_B:0));
    }
    else
    {
        enc_ticks[0] = enc_ticks[1] = enc_ticks[2] = 0;
    }

    prev_enc_status = encoders_status;

}

int main(void)
{

    SysCtlClockSet(SYSCTL_SYSDIV_4|SYSCTL_USE_PLL|SYSCTL_XTAL_16MHZ|SYSCTL_OSC_MAIN);

    cLedInit();
    cLedSet(LED_R);

    setup();

    cLedSet(LED_G);
    while(1)
    {
        loop();
    }
}

void UART0Handler()
{
    
    uint32_t status = UARTIntStatus(UART0_BASE, true); 
    
    UARTIntClear( UART0_BASE, status );
    
    if(status & UART_INT_RX)
    {
        // do nothing here too
        
    }
    
    if(status & UART_INT_TX)
    {
        // do nothing here
    }
}

int uart_send(void *buf, int bytes, void *usr)
{
    char *charbuf = (char*) buf;
    for(int i = 0; i < bytes; i++)
    {
        UARTCharPut( UART0_BASE, charbuf[i] );       
    }
    
    return 0;
}

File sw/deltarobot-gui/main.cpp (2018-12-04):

#include <QGuiApplication>
#include <QQmlApplicationEngine>
#include <QQmlContext>

#include "libdeltarobot/protocol.h"
#include "libdeltarobot/protocol_pc_utils.h"
#include "libdeltarobot/deltarobot.h"

#include <QtSerialPort/QSerialPort>
#include <QVector3D>
#include <QDebug>


class deltarobot_connection : public QObject
{
Q_OBJECT
Q_PROPERTY(bool connected READ isConnected NOTIFY connectedChanged)

public:
    deltarobot_connection()
    : m_sp()
    {
        m_sp.setBaudRate(115200);
        m_sp.setPortName("/dev/ttyACM0");
        m_sp.open(QIODevice::ReadWrite);
        
        connect(&m_sp, &QSerialPort::readyRead, this,
                    &deltarobot_connection::onReadyRead);
            
        emit connectedChanged(isConnected());

    }
    
    int sendfunc( void *data, int bytes, void*me )
    {
        return ((deltarobot_connection*)me)->send_bytes(data, bytes);
    }
    
    int send_bytes( void *data, int bytes)
    {
        if(m_sp.isOpen())
        {
            m_sp.write((const char*)data, bytes);
            m_sp.flush();
        }
        else return -1;
    }
    
public slots:
    void onReadyRead()
    {
        QByteArray all = m_sp.readAll();
        if(!all.size())
            return;
        emit messageReceivedStr(QString("%1 bytes").arg(all.size()));
        dp_process(&m_pd, all.data(), all.size());
        
        protocol_msg msg;
        int res;

        while(!(res = dp_recv(&m_pd, &msg)))
        {
            if(!msg.checksum_ok)
                qDebug("checksum error\n");
            else
            {
                // received a valid message
                switch(msg.opcode)
                {
                    case DP_OPCODE_ACK:
                        emit ackReceived(msg.data_s? msg.data[0] : -1);
                    case DP_OPCODE_NACK:
                        emit nackReceived(msg.data_s? msg.data[0] : -1);
                    case DP_OPCODE_HOMING_REPL:
                        emit homingFinished();
                    case DP_OPCODE_MOVE_REPL:
                        emit moveFinished();
                    case DP_OPCODE_STATUS_REPL:
                        readStatus(msg);
                    case DP_OPCODE_GENERAL_ERR:
                        emit generalError();
                }

                // also emit the received text
                emit messageReceivedStr( QString::fromStdString( deltarobot::protocol_msg_to_str(&msg) ) );
            }
        }
    }
    
    void sendAck(int opcode) 
    { 
        protocol_msg m;
        m.opcode = DP_OPCODE_ACK;
        m.data_s = 1;
        m.data[0] = (unsigned char) opcode;
        
        sendMsg( m );
    }
    
    void sendNack(int opcode)
    {
        protocol_msg m;
        m.opcode = DP_OPCODE_NACK;
        m.data_s = 1;
        m.data[0] = (unsigned char) opcode;

        sendMsg( m );
    }

    void sendHome()
    {
        protocol_msg m;
        m.opcode = DP_OPCODE_HOMING;
        m.data_s = 0;

        sendMsg( m );
    }

    void sendCancel()
    {
        protocol_msg m;
        m.opcode = DP_OPCODE_CANCEL;
        m.data_s = 0;

        sendMsg( m );
    }

    void sendMove(float a, float b, float c)
    {
        if(qIsNaN(a) || qIsNaN(b) || qIsNaN(c))
        {
            emit messageSentStr("Denied. Cannot move to nan position.");
            return;
        }

        protocol_msg m;
        m.opcode = DP_OPCODE_MOVE;
        m.data_s = sizeof(protocol_msg_position);
        protocol_msg_position *pos = (protocol_msg_position *) m.data;

        pos->DA = a;
        pos->DB = b;
        pos->DC = c;

        sendMsg( m );
    }

    void askStatus()
    {
        protocol_msg m;
        m.opcode = DP_OPCODE_STATUS;
        m.data_s = 0;

        sendMsg( m );
    }
    
    void sendMsg( protocol_msg &m )
    {
        dp_send( &m, &messageWrite, (void*) this);

        emit messageSentStr( QString::fromStdString( deltarobot::protocol_msg_to_str(&m) ) + QString(", %1 data bytes").arg(m.data_s)  );
    }

    static int messageWrite( void *buf, int bytes, void *usr )
    {
        deltarobot_connection* me = (deltarobot_connection*) usr;

        return me->m_sp.write( (const char *) buf, bytes );
    }

    bool isConnected() { return m_sp.isOpen(); }
public:
    
signals:
    void connectedChanged( bool c );
    
    void ackReceived( char opcode );
    void nackReceived( char opcode );
    void homingFinished();
    void moveFinished();
    void statusReply(int status, bool stopa, float a, bool stopb, float b, bool stopc, float c);
    void generalError();
    
    void messageReceivedStr( QString msg );
    void messageSentStr( QString msg );

private:
    void readStatus(const protocol_msg &msg)
    {
        if(msg.data_s < 13)
        {
            printf("malformed status! data size is %d, expected at least 13 \n", msg.data_s);
            return;
        }
        
        float a = *(float*)( msg.data + 0 );
        float b = *(float*)( msg.data + 4 );
        float c = *(float*)( msg.data + 8 );
        
        int st = msg.data[12] & 0b11;
        int stops = msg.data[12] >> 2;
        
        emit statusReply(st, stops&0b001, a, stops&0b010, b, stops&0b100, c);
    }

    QSerialPort m_sp;
    protocol_data m_pd;
};

QVector3D toQt(const deltarobot::vec3 &v)
{
    return QVector3D(v[0], v[1], v[2]);
}

deltarobot::vec3 toLib(const QVector3D &v)
{
    return deltarobot::vec3(v.x(), v.y(), v.z());
}

class deltarobot_model : public QObject
{
    Q_OBJECT
    Q_PROPERTY(QVector3D armAPos READ armAPos WRITE setArmAPos NOTIFY armAPosChanged)
    Q_PROPERTY(QVector3D armBPos READ armBPos WRITE setArmBPos NOTIFY armBPosChanged)
    Q_PROPERTY(QVector3D armCPos READ armCPos WRITE setArmCPos NOTIFY armCPosChanged)
    Q_PROPERTY(double dB1B3 READ dB1B3 WRITE setDB1B3 NOTIFY dB1B3Changed)
    Q_PROPERTY(double dE READ dE WRITE setDE NOTIFY dEChanged)
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

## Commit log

2018-03-22 first file dump, structure definition
    [deltarobot.kicad_pcb, deltarobot.sch]
2018-03-28 [hw] defined uC pinout and connectivity
    [deltarobot.sch]
2018-06-29 Huge code dump
    [deltarobot.sch]
2018-06-29 added thru-hole adapter for smd mosfet driver
    [fet-driver-adapter.kicad_pcb, fet-driver-adapter.sch]
2018-06-29 added motor driver pcb
    [deltarobot-driver.kicad_pcb, deltarobot-driver.sch]
2018-12-04 3d print parts for motor replacement, first working version of sotfware and firmware
    [assembly.fcstd, axle_adapter.fcstd, led5mm.fcstd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]
